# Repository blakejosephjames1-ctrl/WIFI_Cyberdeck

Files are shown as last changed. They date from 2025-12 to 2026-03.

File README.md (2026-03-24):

# About Project
This project is a Cyberdeck -style WiFi experimentation and penetration testing device based on an ESP32 -s3 microcontroller. Desighned on KiCad.

The device is commpatible to run EPS32 marauder https://github.com/justcallmekoko/ESP32Marauder.git (NOT TO BE USED FOR UNAUTHORISED PEN-TESTING)



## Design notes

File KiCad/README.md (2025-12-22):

## About
This folder contains all of the KiCad files for my project the files here are for the Micro controler for my project. My final product will consist of a microcontroler touchscreen battery and case however the KiCad files here only contain the microcontroler. The touch screen will be attached through GPIO pins and the battery through the designated connections so i did not have anything to include in the KiCad files for these components. The board has additiional memory so that heavyer weight opperating systems and programs can be ran on the device expanding the deviecs capabilitys.

### Images

#### MCU


#### GPIO pins


#### Power


#### USB -C


#### Voltage regulation


#### Battery charging 


#### Additonal memory


### PCB


## 3D model 


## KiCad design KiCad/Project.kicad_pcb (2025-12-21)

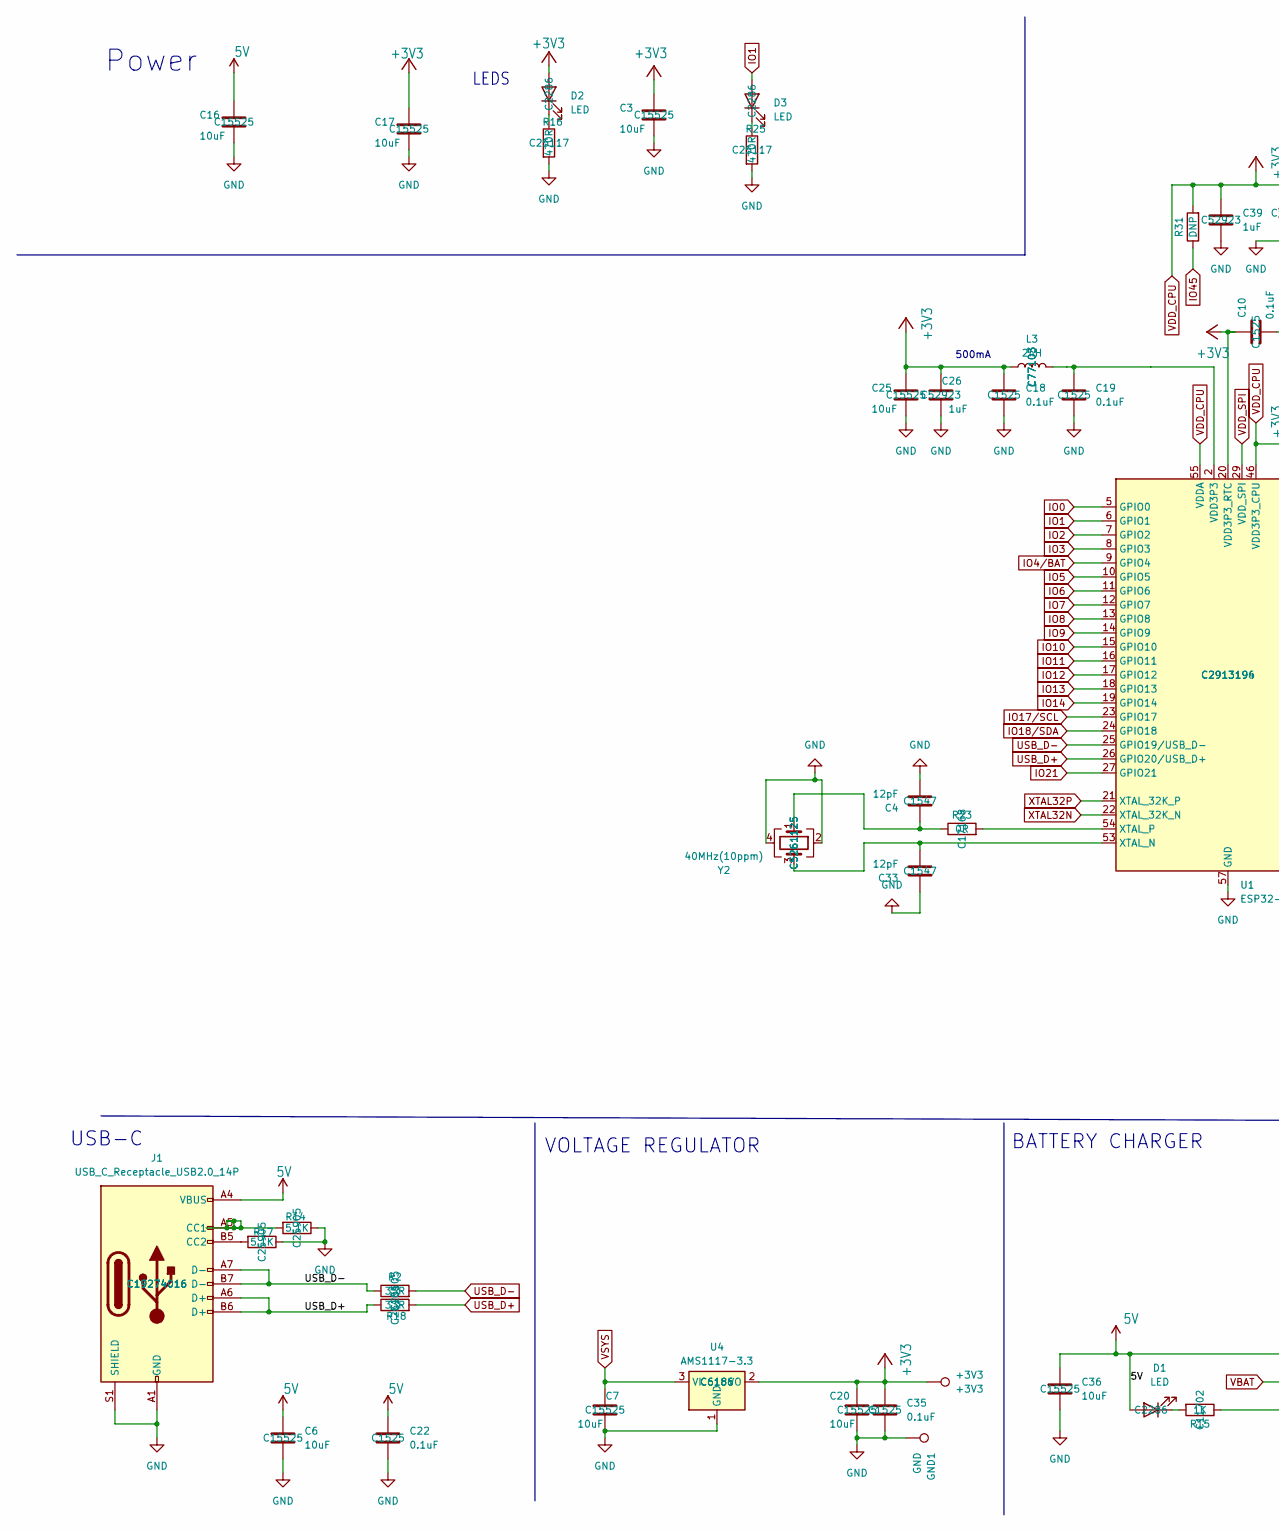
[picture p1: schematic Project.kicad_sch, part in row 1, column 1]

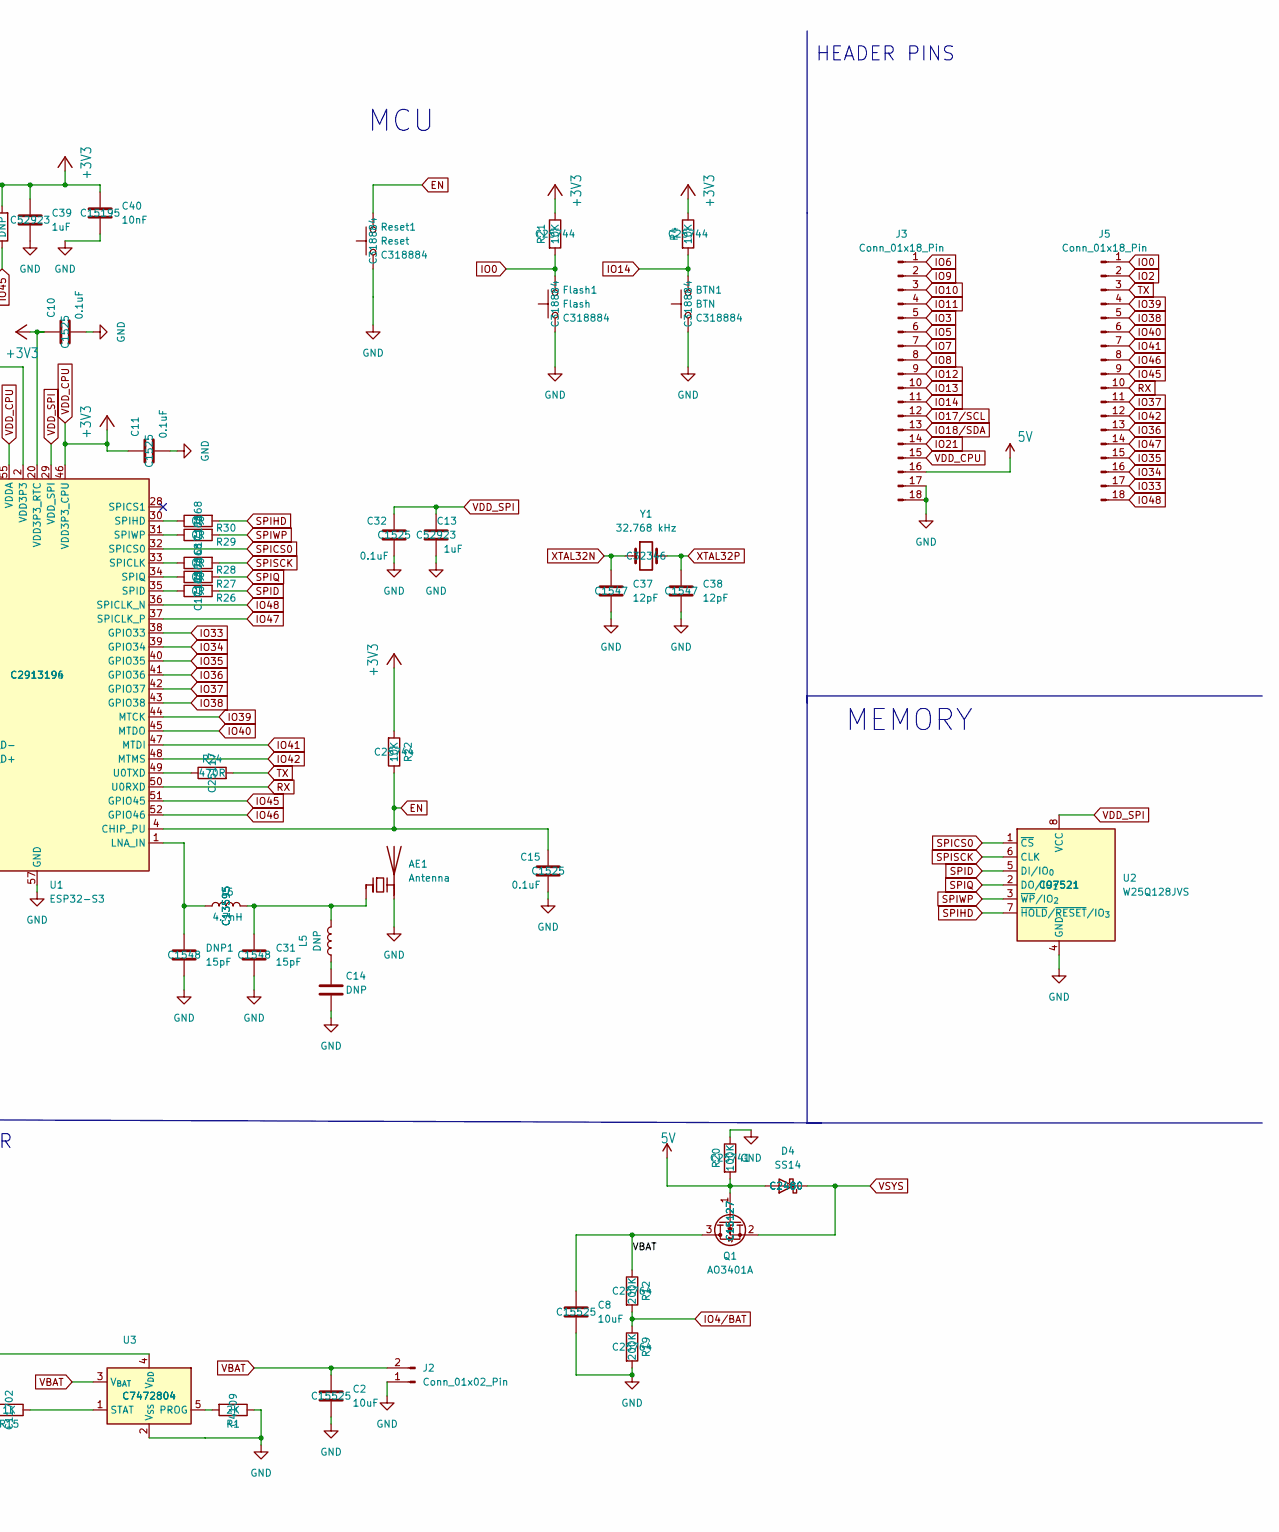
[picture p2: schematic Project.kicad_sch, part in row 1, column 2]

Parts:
+3V3: +3V3; TestPoint_Pad_D1.0mm
AE1: Antenna; Texas_SWRA117D_2.4GHz_Left
BTN1: BTN; SW_Push_1P1T_XKB_TS-1187A; MNF PART NUMBER C318884; LCSC C318884
C2, C3, C6, C7, C8, C16, C17, C20, C25, C36: 10uF; C_0402_1005Metric; MNF PART NUMBER C15525; LCSC C15525
C4, C33, C37, C38: 12pF; C_0402_1005Metric; MNF PART NUMBER C1547; LCSC C1547
C10, C11, C15, C18, C19, C22, C32, C35: 0.1uF; C_0402_1005Metric; MNF PART NUMBER C1525; LCSC C1525
C13, C26, C39: 1uF; C_0402_1005Metric; MNF PART NUMBER C52923; LCSC C52923
C14: DNP; C_0402_1005Metric
C31: 15pF; C_0402_1005Metric; MNF PART NUMBER C1548; LCSC C1548
C40: 10nF; C_0402_1005Metric; MNF PART NUMBER C15195; LCSC C15195
D1, D2, D3: LED; LED_0603_1608Metric; MNF PART NUMBER C2286; LCSC C2286
D4: SS14; D_SMA; MNF PART NUMBER C2480; LCSC C2480
DNP1: 15pF; C_0402_1005Metric; MNF PART NUMBER C1548; LCSC C1548
Flash1: Flash; SW_Push_1P1T_XKB_TS-1187A; MNF PART NUMBER C318884; LCSC C318884
GND1: GND; TestPoint_Pad_D1.0mm
J1: USB_C_Receptacle_USB2.0_14P; USB_C_Receptacle_HCTL_HC-TYPE-C-16P-01A; MNF PART NUMBER C19274016; LCSC C19274016
J2: Conn_01x02_Pin; PinSocket_1x02_P2.54mm_Vertical
J3, J5: Conn_01x18_Pin; PinHeader_1x18_P2.54mm_Vertical
L3: 2nH; L_0402_1005Metric; MNF PART NUMBER C77103; LCSC C77103
L5: DNP; L_0402_1005Metric
L6: 4.7nH; L_0402_1005Metric; MNF PART NUMBER C13595; LCSC C13595
Q1: AO3401A; SOT-23; MNF PART NUMBER C15127; LCSC C15127
R1: 2K; R_0402_1005Metric; MNF PART NUMBER C4109; LCSC C4109
R2, R18: 33R; R_0402_1005Metric; MNF PART NUMBER C25105; LCSC C25105
R4, R21, R22: 10K; R_0402_1005Metric; MNF PART NUMBER C25744; LCSC C25744
R12, R19: 200K; R_0402_1005Metric; MNF PART NUMBER C25764; LCSC C25764
R14, R17: 5.1K; R_0402_1005Metric; MNF PART NUMBER C25905; LCSC C25905
R15: 1K; R_0402_1005Metric; MNF PART NUMBER C11702; LCSC C11702
R16, R24, R25: 470R; R_0402_1005Metric; MNF PART NUMBER C25117; LCSC C25117
R20: 100K; R_0402_1005Metric; MNF PART NUMBER C25741; LCSC C25741
R23, R26, R27, R28, R29, R30: 0R; R_0402_1005Metric; MNF PART NUMBER C17168; LCSC C17168
R31: DNP; R_0402_1005Metric
Reset1: Reset; SW_Push_1P1T_XKB_TS-1187A; MNF PART NUMBER C318884; LCSC C318884
U1: ESP32-S3; QFN-56-1EP_7x7mm_P0.4mm_EP4x4mm; MNF PART NUMBER C2913196; LCSC C2913194
U2: W25Q128JVS; SOIC-8_5.3x5.3mm_P1.27mm; MNF PART NUMBER C97521; LCSC C97521
U3: MCP73831-2-OT; SOT-23-5; MNF PART NUMBER C7472804; LCSC C7472804
U4: AMS1117-3.3; SOT-223-3_TabPin2; MNF PART NUMBER C6186; LCSC C6186
Y1: 32.768 kHz; Crystal_SMD_3215-2Pin_3.2x1.5mm; MNF PART NUMBER C32346; LCSC C32346
Y2: 40MHz(10ppm); Crystal_SMD_2520-4Pin_2.5x2.0mm; MNF PART NUMBER C5261125; LCSC C5261125

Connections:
5V: C6.1, C16.1, C22.1, C36.1, D1.2 (A), D4.2 (A), J1.A4 (VBUS), J1.A9 (VBUS), J1.B4 (VBUS), J1.B9 (VBUS), J3.16, Q1.1 (G), R20.2, U3.4 (V_{DD})
EN: C15.1, R22.1, Reset1.2, U1.4 (CHIP_PU)
GND: AE1.2 (PCB_Trace), BTN1.1, C2.2, C3.2, C4.2, C6.2, C7.2, C8.2, C10.2, C11.2, C13.2, C14.2, C15.2, C16.2, C17.2, C18.2, C19.2, C20.2, C22.2, C25.2, C26.2, C31.2, C32.2, C33.1, C35.2, C36.2, C37.2, C38.2, C39.2, C40.2, DNP1.2, Flash1.1, GND1.1, J1.A1 (GND), J1.A12 (GND), J1.B1 (GND), J1.B12 (GND), J1.S1 (SHIELD), J2.1, J3.17, J3.18, R1.1, R14.1, R16.2, R17.1, R19.2, R20.1, R25.2, Reset1.1, U1.57 (GND), U2.4 (GND), U3.2 (V_{SS}), U4.1 (GND), Y2.2, Y2.4
IO0: Flash1.2, J5.1, R21.2, U1.5 (GPIO0)
IO1: D3.2 (A), U1.6 (GPIO1)
IO2: J5.2, U1.7 (GPIO2)
IO3: J3.5, U1.8 (GPIO3)
IO4/BAT: R12.2, R19.1, U1.9 (GPIO4)
IO5: J3.6, U1.10 (GPIO5)
IO6: J3.1, U1.11 (GPIO6)
IO7: J3.7, U1.12 (GPIO7)
IO8: J3.8, U1.13 (GPIO8)
IO9: J3.2, U1.14 (GPIO9)
IO10: J3.3, U1.15 (GPIO10)
IO11: J3.4, U1.16 (GPIO11)
IO12: J3.9, U1.17 (GPIO12)
IO13: J3.10, U1.18 (GPIO13)
IO14: BTN1.2, J3.11, R4.2, U1.19 (GPIO14)
IO17/SCL: J3.12, U1.23 (GPIO17)
IO18/SDA: J3.13, U1.24 (GPIO18)
IO21: J3.14, U1.27 (GPIO21)
IO33: J5.17, U1.38 (GPIO33)
IO34: J5.16, U1.39 (GPIO34)
IO35: J5.15, U1.40 (GPIO35)
IO36: J5.13, U1.41 (GPIO36)
IO37: J5.11, U1.42 (GPIO37)
IO38: J5.5, U1.43 (GPIO38)
IO39: J5.4, U1.44 (MTCK)
IO40: J5.6, U1.45 (MTDO)
IO41: J5.7, U1.47 (MTDI)
IO42: J5.12, U1.48 (MTMS)
IO45: J5.9, R31.1, U1.51 (GPIO45)
IO46: J5.8, U1.52 (GPIO46)
IO47: J5.14, U1.37 (SPICLK_P)
IO48: J5.18, U1.36 (SPICLK_N)
unnamed: AE1.1 (FEED), C31.1, L5.2, L6.2
unnamed: C4.1, R23.1, Y2.1
unnamed: C14.1, L5.1
unnamed: C19.1, L3.2, U1.2 (VDD3P3), U1.3 (VDD3P3)
unnamed: D1.1 (K), R15.2
unnamed: D2.1 (K), R16.1
unnamed: D3.1 (K), R25.1
unnamed: J1.A5 (CC1), R14.2
unnamed: J1.B5 (CC2), R17.2
unnamed: DNP1.1, L6.1, U1.1 (LNA_IN)
unnamed: R28.1, U1.33 (SPICLK)
unnamed: R26.1, U1.35 (SPID)
unnamed: R30.1, U1.30 (SPIHD)
unnamed: R27.1, U1.34 (SPIQ)
unnamed: R29.1, U1.31 (SPIWP)
unnamed: R24.1, U1.49 (U0TXD)
unnamed: C33.2, U1.53 (XTAL_N), Y2.3
unnamed: R23.2, U1.54 (XTAL_P)
unnamed: R1.2, U3.5 (PROG)
unnamed: R15.1, U3.1 (STAT)
RX: J5.10, U1.50 (U0RXD)
SPICS0: U1.32 (SPICS0), U2.1 (~CS)
SPID: R26.2, U2.5 (DI/IO_{0})
SPIHD: R30.2, U2.7 (~HOLD/~RESET/IO_{3})
SPIQ: R27.2, U2.2 (DO/IO_{1})
SPISCK: R28.2, U2.6 (CLK)
SPIWP: R29.2, U2.3 (~WP/IO_{2})
TX: J5.3, R24.2
USB_D+: J1.A6 (D+), J1.B6 (D+), R18.1, R18.2, U1.26 (GPIO20/USB_D+)
USB_D-: J1.A7 (D-), J1.B7 (D-), R2.1, R2.2, U1.25 (GPIO19/USB_D-)
VBAT: C2.1, C8.1, J2.2, Q1.3 (D), R12.1, U3.3 (V_{BAT})
VDD_CPU: +3V3.1, C3.1, C10.1, C11.1, C17.1, C18.1, C20.1, C25.1, C26.1, C35.1, C39.1, C40.1, D2.2 (A), J3.15, L3.1, R4.1, R21.1, R22.2, R31.2, U1.20 (VDD3P3_RTC), U1.46 (VDD3P3_CPU), U1.55 (VDDA), U1.56 (VDDA), U4.2 (VO)
VDD_SPI: C13.1, C32.1, U1.29 (VDD_SPI), U2.8 (VCC)
VSYS: C7.1, D4.1 (K), Q1.2 (S), U4.3 (VI)
XTAL32N: C37.1, U1.22 (XTAL_32K_N), Y1.1
XTAL32P: C38.1, U1.21 (XTAL_32K_P), Y1.2

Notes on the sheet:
BATTERY CHARGER
VOLTAGE REGULATOR
500mA
LEDS
HEADER PINS
MEMORY
Power
USB-C
MCU

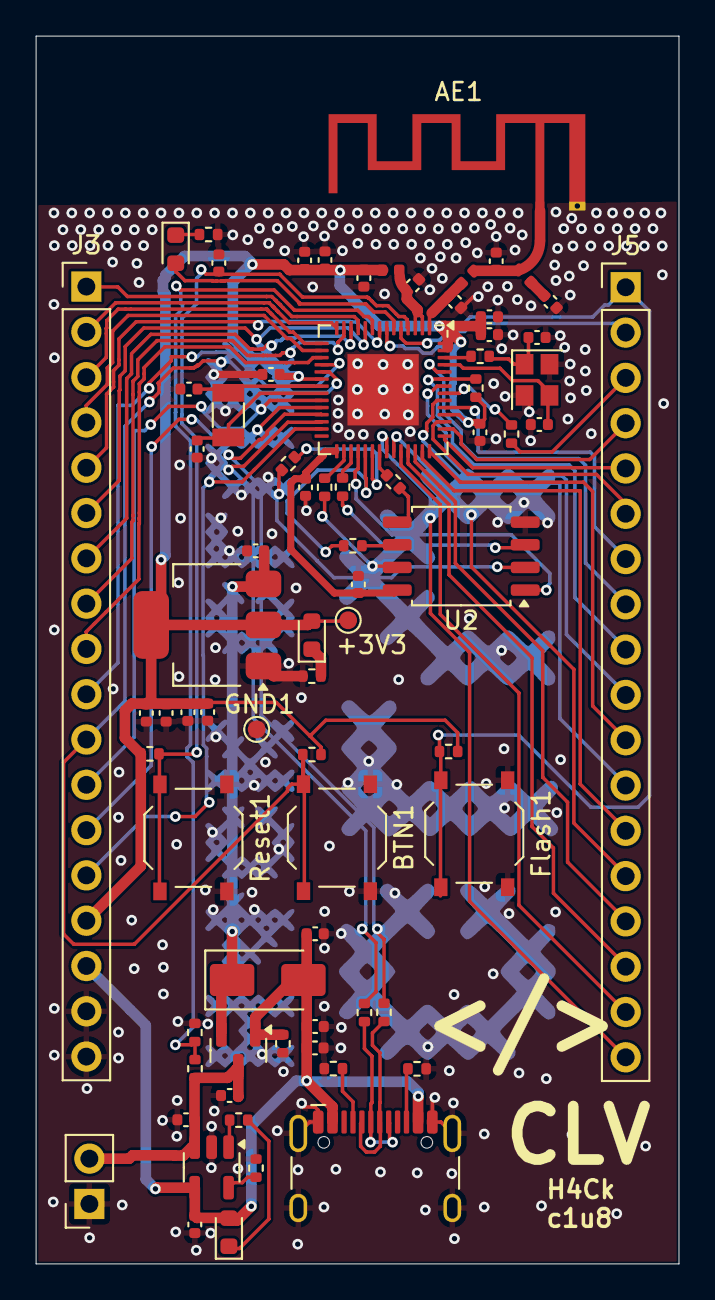
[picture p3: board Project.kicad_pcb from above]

Board: 2 copper layers, 36.0 x 68.8 mm, 75 parts (0 on the bottom side), 71 nets.

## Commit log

2025-12-20 Create .gitignore for KiCad project
    Add .gitignore file for KiCad project files and temporary files.
2025-12-21 KiCad Files uploaded
    [Project.kicad_pcb, Project.kicad_sch]
